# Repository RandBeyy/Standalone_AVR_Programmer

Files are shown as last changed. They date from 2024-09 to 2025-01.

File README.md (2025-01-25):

This project is based on Nick Gammon's ATmega_Hex_Uploader.
I added the LCD2004 to the project and design PCB so this device look more decent.
The main reason of this project is to make a small device to program a lot of MCUs like Attiny45
with simple and easy interface and without a computer. 
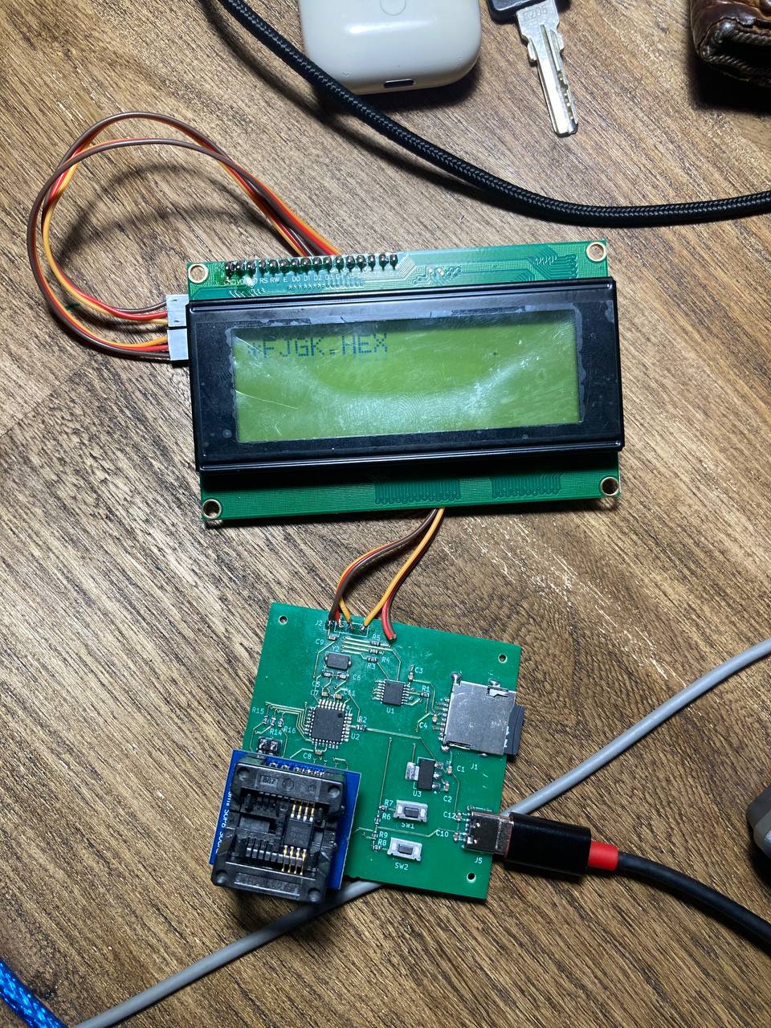
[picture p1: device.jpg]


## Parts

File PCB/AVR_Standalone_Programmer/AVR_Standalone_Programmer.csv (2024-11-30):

Id | Designator | Footprint | Quantity | Designation | Supplier and ref
1 | R4,R1,R3,R5 | R_0603_1608Metric | 4 | 3.3k
2 | R14,R16,R15 | R_0603_1608Metric | 3 | 330R
3 | C9,C10,C2,C12,C8 | C_0603_1608Metric | 5 | 10uF
4 | U2 | TQFP-32_7x7mm_P0.8mm | 1 | ATmega328P-A
5 | J1 | CUI_MSD-3-A | 1 | MSD-3-A
6 | H1,H3,H4,H2 | MountingHole_2.2mm_M2 | 4 | MountingHole
7 | R11,R13,R10,R12 | R_0603_1608Metric | 4 | 0R
8 | J4,J3 | PinSocket_1x04_P2.54mm_Vertical | 2 | Conn_01x04_Socket
9 | R8,R2,R7 | R_0603_1608Metric | 3 | 1k
10 | U3 | SOT-223-3_TabPin2 | 1 | LD1117S33TR_SOT223
11 | C11,C1,C3,C4,C7 | C_0603_1608Metric | 5 | 100nF
12 | J5 | USB_C_Receptacle_GCT_USB4125-xx-x_6P_TopMnt_Horizontal | 1 | USB_C_Receptacle_PowerOnly_6P
13 | U1 | SOT402-1_NEX | 1 | 74LVC125APW
14 | C6,C5 | C_0805_2012Metric | 2 | 22uF
15 | J6 | PinHeader_2x03_P2.54mm_Vertical | 1 | AVR-ISP-6
16 | J2 | PinHeader_1x04_P2.54mm_Vertical | 1 | Conn_01x04_Pin
17 | SW1,SW2 | SW_Push_SPST_NO_Alps_SKRK | 2 | SW_DPST_x2
18 | R17 | R_0603_1608Metric | 1 | 100
19 | R6,R9 | R_0603_1608Metric | 2 | 10k
20 | Y2 | Crystal_SMD_5032-2Pin_5.0x3.2mm | 1 | 16Mhz

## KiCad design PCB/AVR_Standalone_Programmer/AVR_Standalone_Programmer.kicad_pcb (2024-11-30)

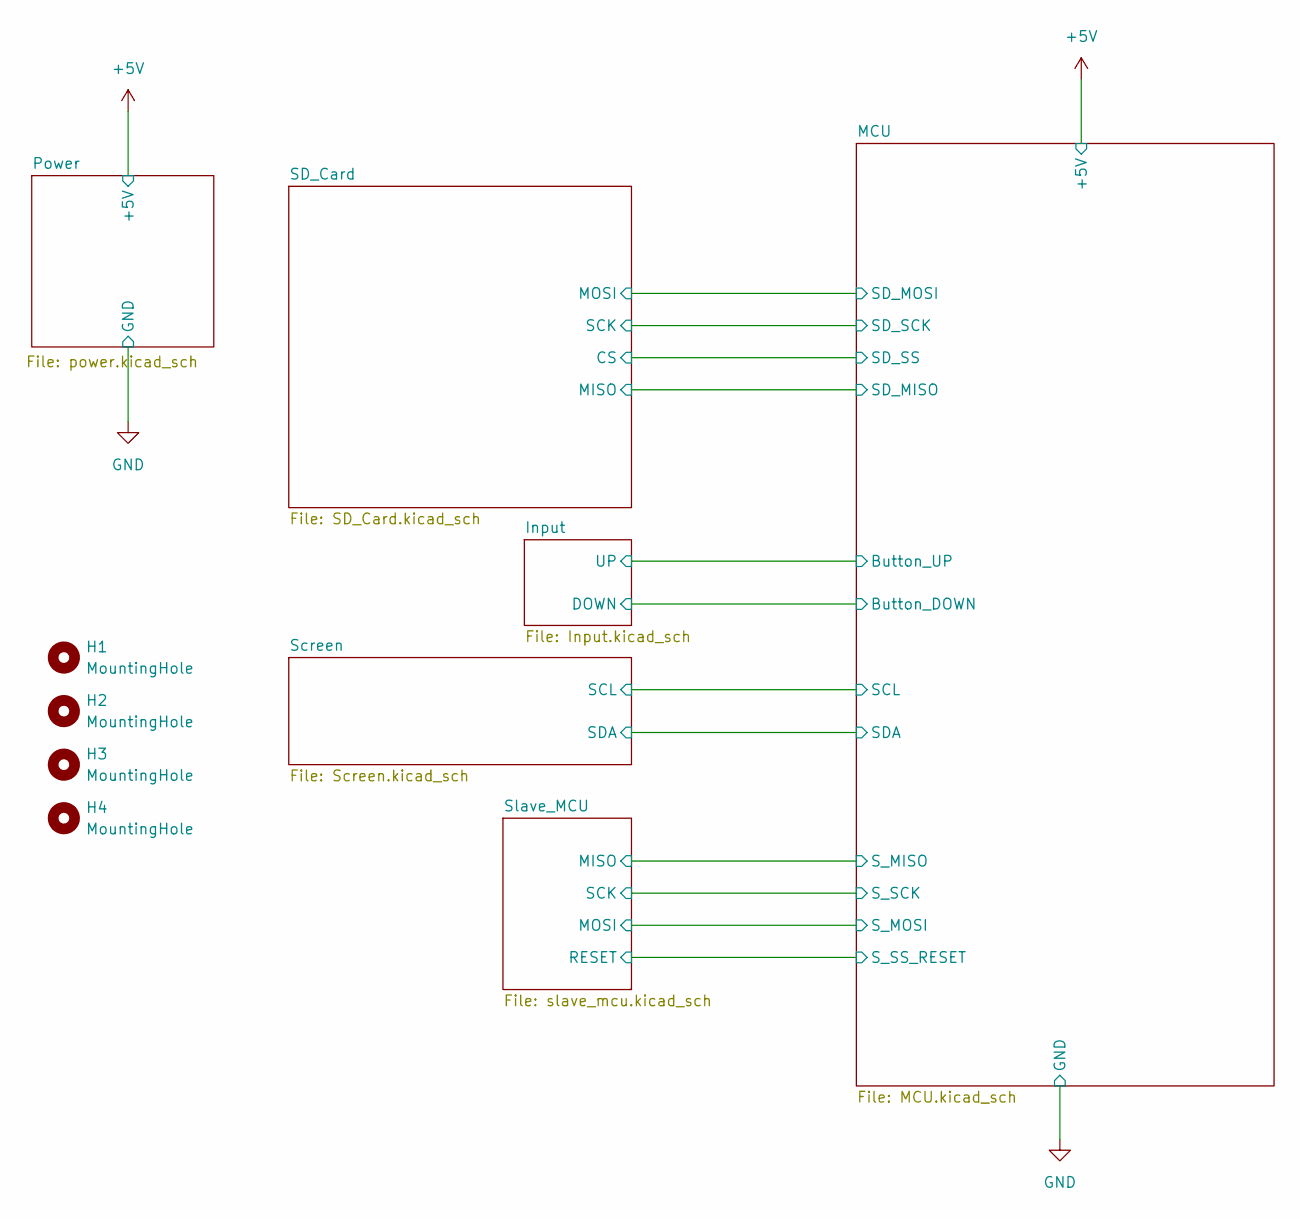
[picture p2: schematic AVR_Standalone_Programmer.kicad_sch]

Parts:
H1, H2, H3, H4: MountingHole; MountingHole_2.2mm_M2

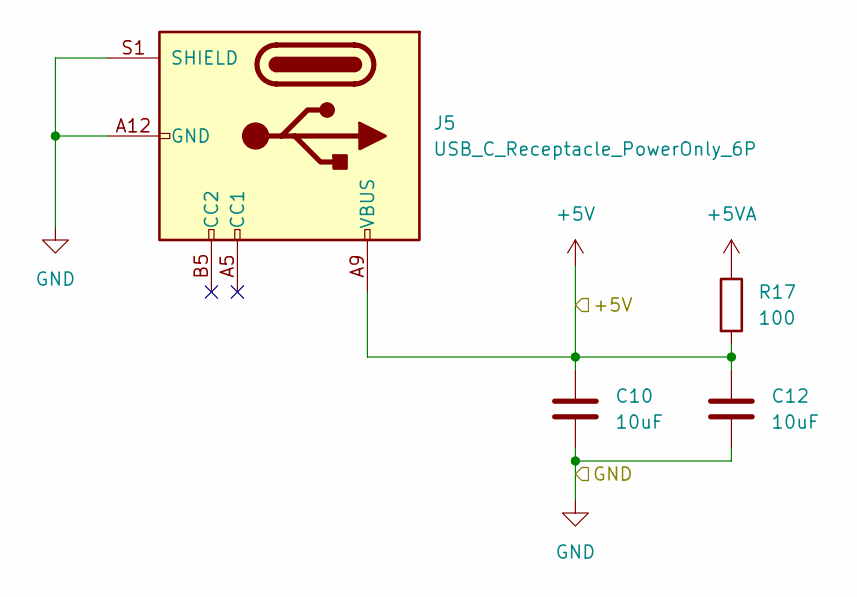
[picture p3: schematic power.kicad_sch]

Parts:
C10, C12: 10uF; C_0603_1608Metric
J5: USB_C_Receptacle_PowerOnly_6P; USB_C_Receptacle_GCT_USB4125-xx-x_6P_TopMnt_Horizontal
R17: 100; R_0603_1608Metric

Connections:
+5V: C10.1, C12.1, J5.A9 (VBUS), J5.B9 (VBUS), R17.2; also elsewhere on the board
+5VA: R17.1; also elsewhere on the board
GND: C10.2, C12.2, J5.A12 (GND), J5.B12 (GND), J5.S1 (SHIELD); also elsewhere on the board

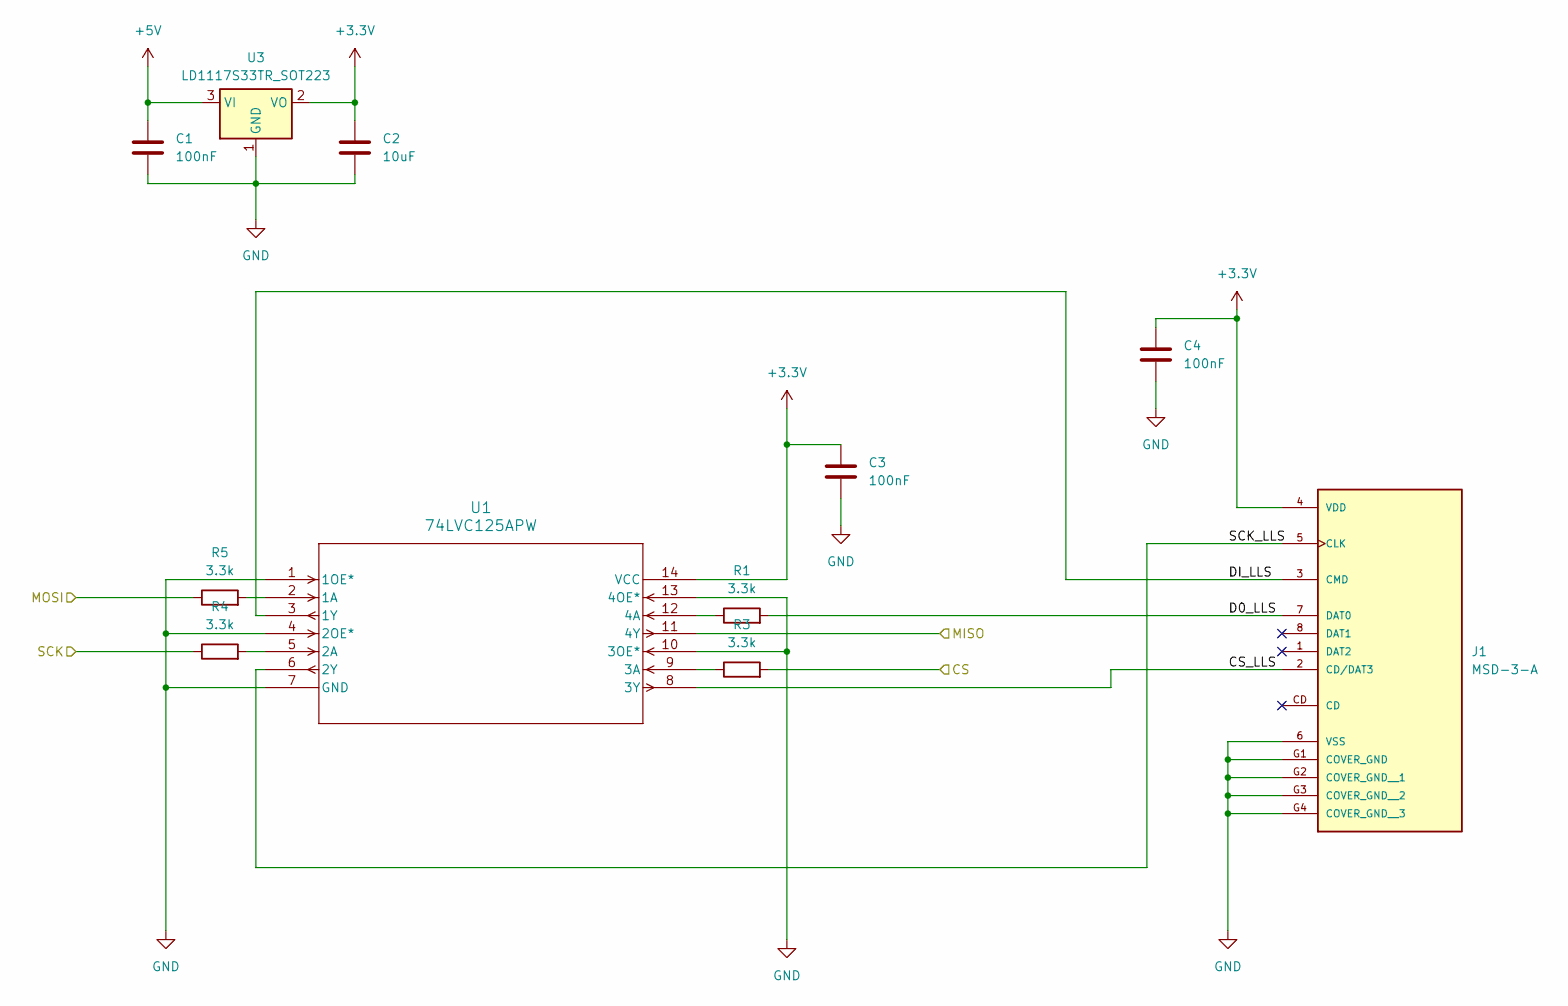
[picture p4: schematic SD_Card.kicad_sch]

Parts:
C1, C3, C4: 100nF; C_0603_1608Metric
C2: 10uF; C_0603_1608Metric
J1: MSD-3-A; CUI_MSD-3-A; PARTREV 1.0
R1, R3, R4, R5: 3.3k; R_0603_1608Metric
U1: 74LVC125APW; SOT402-1_NEX
U3: LD1117S33TR_SOT223; SOT-223-3_TabPin2

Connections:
+3.3V: C2.1, C3.1, C4.1, J1.4 (VDD), U1.14 (VCC), U3.2 (VO)
+5V: C1.1, U3.3 (VI); also elsewhere on the board
/MCU/MISO: U1.11 (4Y); also elsewhere on the board
/MCU/MOSI: R5.1; also elsewhere on the board
/MCU/SCK: R4.1; also elsewhere on the board
/MCU/SD_SS: R3.2; also elsewhere on the board
/SD_Card/CS_LLS: J1.2 (CD/DAT3), U1.8 (3Y)
/SD_Card/D0_LLS: J1.7 (DAT0), R1.2
/SD_Card/DI_LLS: J1.3 (CMD), U1.3 (1Y)
/SD_Card/SCK_LLS: J1.5 (CLK), U1.6 (2Y)
GND: C1.2, C2.2, C3.2, C4.2, J1.6 (VSS), J1.G1 (COVER_GND), J1.G2 (COVER_GND__1), J1.G3 (COVER_GND__2), J1.G4 (COVER_GND__3), U1.1 (1OE*), U1.4 (2OE*), U1.7 (GND), U1.10 (3OE*), U1.13 (4OE*), U3.1 (GND); also elsewhere on the board
unnamed: R5.2, U1.2 (1A)
unnamed: R4.2, U1.5 (2A)
unnamed: R3.1, U1.9 (3A)
unnamed: R1.1, U1.12 (4A)

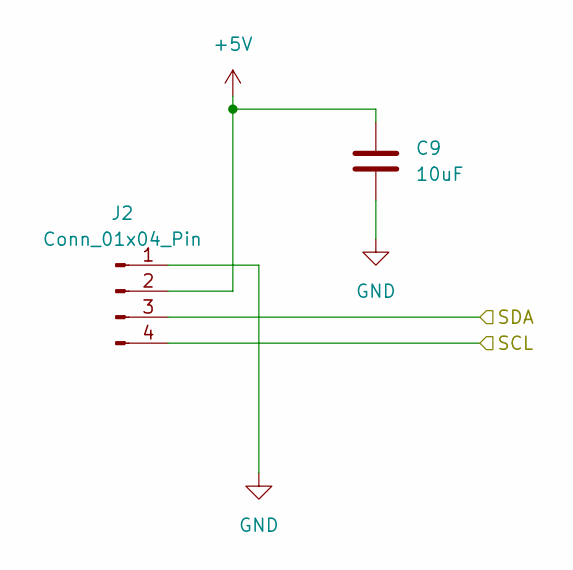
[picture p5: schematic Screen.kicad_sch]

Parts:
C9: 10uF; C_0603_1608Metric
J2: Conn_01x04_Pin; PinHeader_1x04_P2.54mm_Vertical

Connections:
+5V: C9.1, J2.2; also elsewhere on the board
/MCU/SCL: J2.4; also elsewhere on the board
/MCU/SDA: J2.3; also elsewhere on the board
GND: C9.2, J2.1; also elsewhere on the board

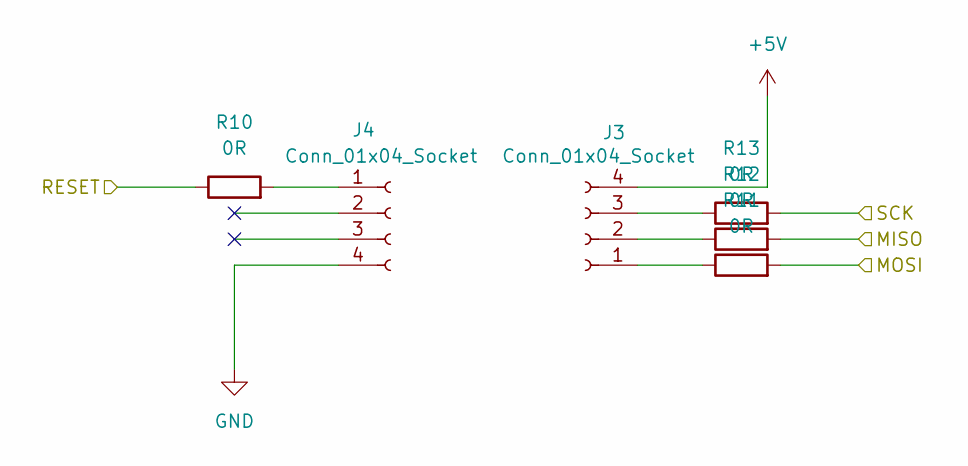
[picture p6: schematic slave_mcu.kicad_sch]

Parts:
J3, J4: Conn_01x04_Socket; PinSocket_1x04_P2.54mm_Vertical
R10, R11, R12, R13: 0R; R_0603_1608Metric

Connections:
+5V: J3.4; also elsewhere on the board
/MCU/S_MISO: R12.2; also elsewhere on the board
/MCU/S_MOSI: R11.2; also elsewhere on the board
/MCU/S_SCK: R13.2; also elsewhere on the board
/MCU/S_SS_RESET: R10.1; also elsewhere on the board
GND: J4.4; also elsewhere on the board
unnamed: J3.1, R11.1
unnamed: J3.2, R12.1
unnamed: J3.3, R13.1
unnamed: J4.1, R10.2

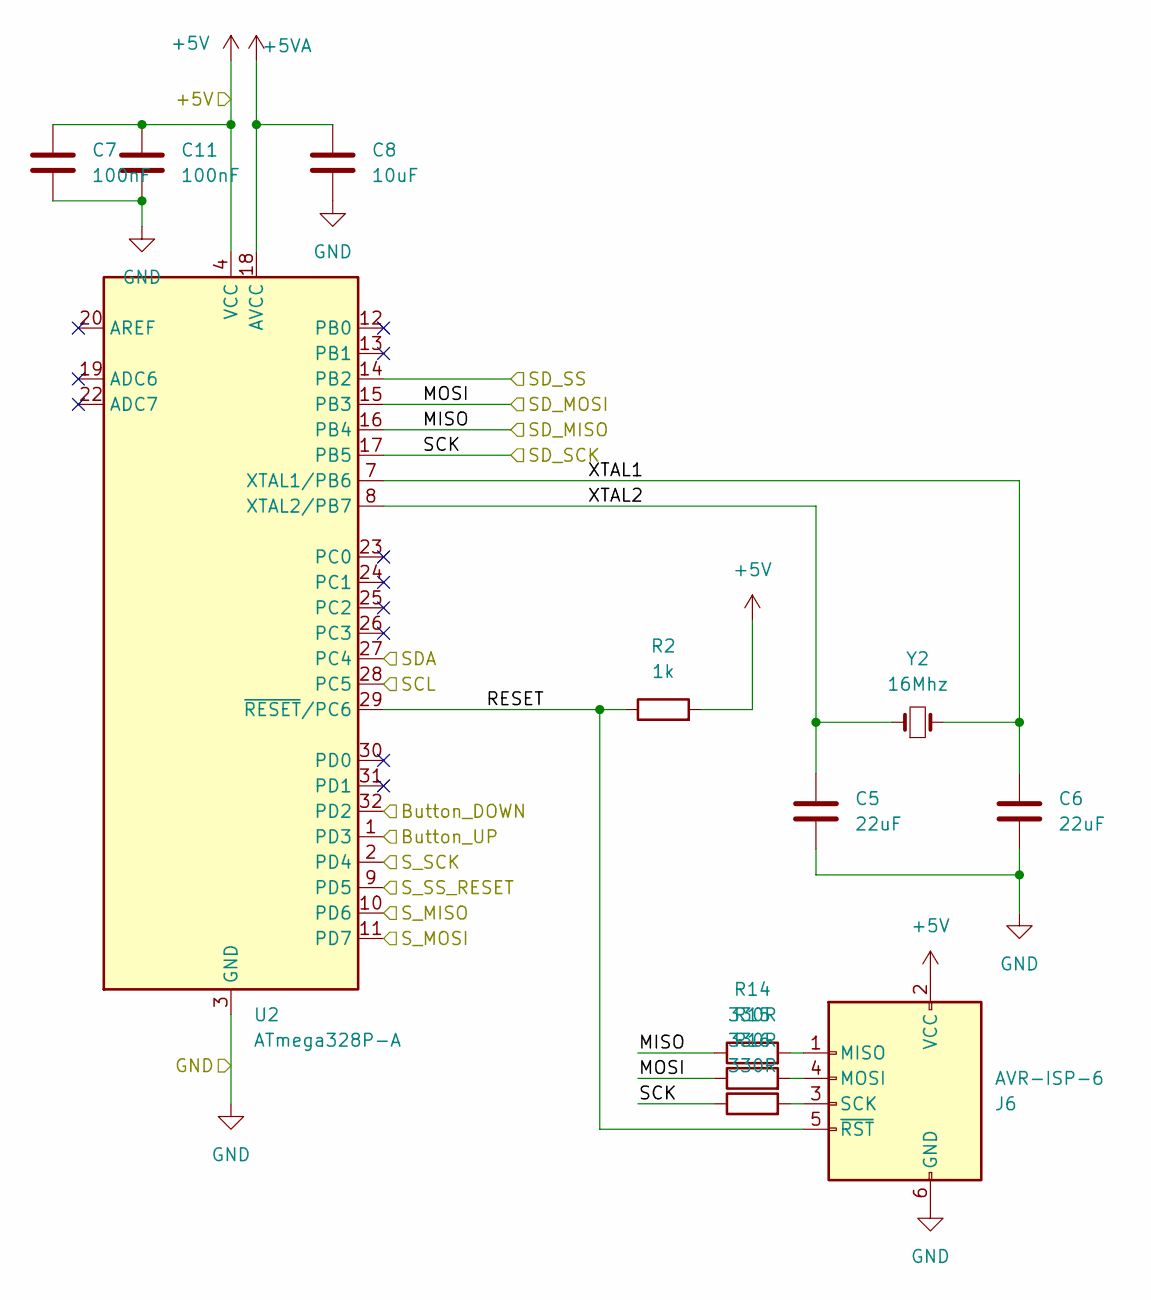
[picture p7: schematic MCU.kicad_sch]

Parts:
C5, C6: 22uF; C_0805_2012Metric
C7, C11: 100nF; C_0603_1608Metric
C8: 10uF; C_0603_1608Metric
J6: AVR-ISP-6; PinHeader_2x03_P2.54mm_Vertical
R2: 1k; R_0603_1608Metric
R14, R15, R16: 330R; R_0603_1608Metric
U2: ATmega328P-A; TQFP-32_7x7mm_P0.8mm
Y2: 16Mhz; Crystal_SMD_5032-2Pin_5.0x3.2mm

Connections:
+5V: C7.1, C11.1, J6.2 (VCC), R2.2, U2.4 (VCC), U2.6 (VCC); also elsewhere on the board
+5VA: C8.1, U2.18 (AVCC); also elsewhere on the board
/Input/DOWN: U2.32 (PD2); also elsewhere on the board
/Input/UP: U2.1 (PD3); also elsewhere on the board
/MCU/MISO: R14.1, U2.16 (PB4); also elsewhere on the board
/MCU/MOSI: R15.1, U2.15 (PB3); also elsewhere on the board
/MCU/RESET: J6.5 (~RST), R2.1, U2.29 (~RESET/PC6)
/MCU/SCK: R16.1, U2.17 (PB5); also elsewhere on the board
/MCU/SCL: U2.28 (PC5); also elsewhere on the board
/MCU/SDA: U2.27 (PC4); also elsewhere on the board
/MCU/SD_SS: U2.14 (PB2); also elsewhere on the board
/MCU/S_MISO: U2.10 (PD6); also elsewhere on the board
/MCU/S_MOSI: U2.11 (PD7); also elsewhere on the board
/MCU/S_SCK: U2.2 (PD4); also elsewhere on the board
/MCU/S_SS_RESET: U2.9 (PD5); also elsewhere on the board
/MCU/XTAL1: C6.1, U2.7 (XTAL1/PB6), Y2.2
/MCU/XTAL2: C5.1, U2.8 (XTAL2/PB7), Y2.1
GND: C5.2, C6.2, C7.2, C8.2, C11.2, J6.6 (GND), U2.3 (GND), U2.5 (GND), U2.21 (GND); also elsewhere on the board
unnamed: J6.1 (MISO), R14.2
unnamed: J6.4 (MOSI), R15.2
unnamed: J6.3 (SCK), R16.2

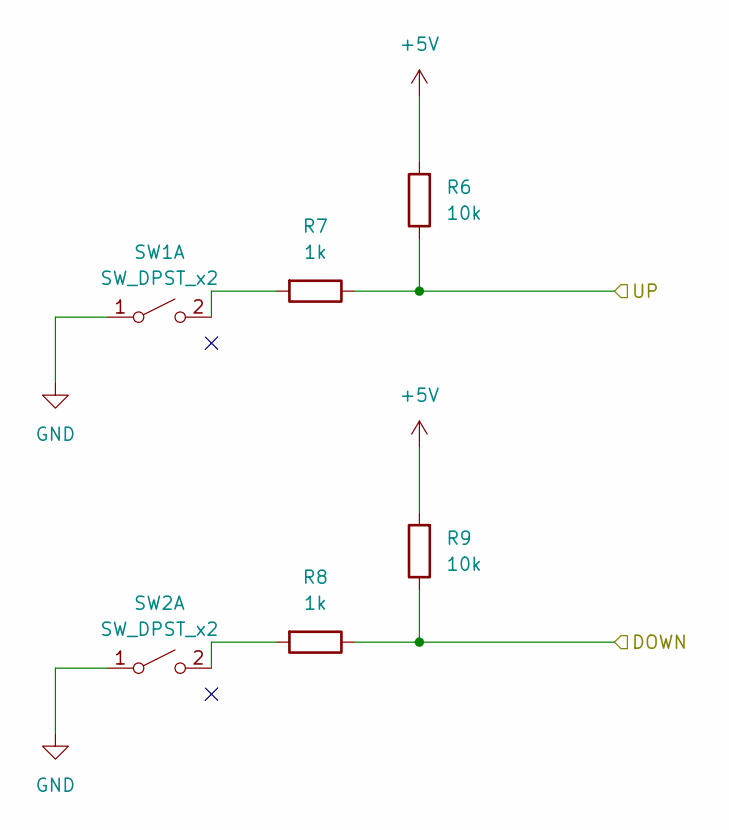
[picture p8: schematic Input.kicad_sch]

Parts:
R6, R9: 10k; R_0603_1608Metric
R7, R8: 1k; R_0603_1608Metric
SW1, SW2: SW_DPST_x2; SW_Push_SPST_NO_Alps_SKRK

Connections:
+5V: R6.2, R9.2; also elsewhere on the board
/Input/DOWN: R8.1, R9.1; also elsewhere on the board
/Input/UP: R6.1, R7.1; also elsewhere on the board
GND: SW1.1 (A), SW2.1 (A); also elsewhere on the board
unnamed: R7.2, SW1.2 (B)
unnamed: R8.2, SW2.2 (B)

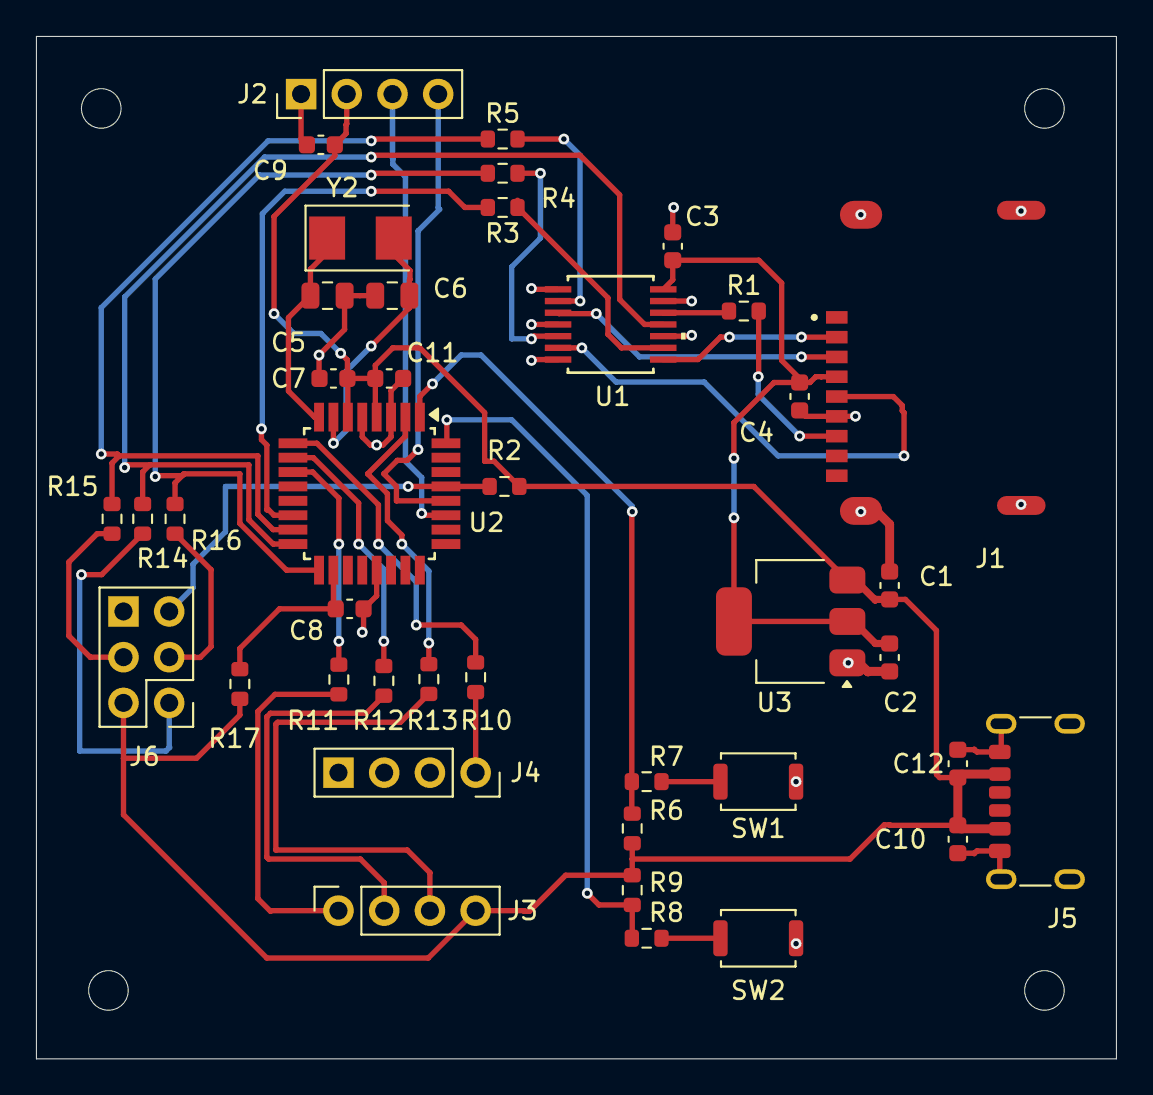
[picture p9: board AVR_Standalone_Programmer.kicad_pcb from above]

Board: 2 copper layers, 60.0 x 56.8 mm, 45 parts (0 on the bottom side), 36 nets.

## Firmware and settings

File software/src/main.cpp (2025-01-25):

const bool allowTargetToRun = true;  // if true, programming lines are freed when not programming

#define ALLOW_MODIFY_FUSES false   // make false if this sketch doesn't fit into memory
#define ALLOW_FILE_SAVING false    // make false if this sketch doesn't fit into memory
#define SAFETY_CHECKS true        // check for disabling SPIEN, or enabling RSTDISBL

#define USE_ETHERNET_SHIELD false  // Use the Arduino Ethernet Shield for the SD card

// make true if you have spare pins for the SD card interface
#define SD_CARD_ACTIVE true

// make true to use the high-voltage parallel wiring
#define HIGH_VOLTAGE_PARALLEL false
// make true to use the high-voltage serial wiring
#define HIGH_VOLTAGE_SERIAL false
// make true to use ICSP programming
#define ICSP_PROGRAMMING true

// make true to use bit-banged SPI for programming
#define USE_BIT_BANGED_SPI true

#if HIGH_VOLTAGE_PARALLEL && HIGH_VOLTAGE_SERIAL
  #error Cannot use both high-voltage parallel and serial at the same time
#endif

#if (HIGH_VOLTAGE_PARALLEL || HIGH_VOLTAGE_SERIAL) && ICSP_PROGRAMMING
  #error Cannot use ICSP and high-voltage programming at the same time
#endif

#if !(HIGH_VOLTAGE_PARALLEL || HIGH_VOLTAGE_SERIAL || ICSP_PROGRAMMING)
  #error Choose a programming mode: HIGH_VOLTAGE_PARALLEL, HIGH_VOLTAGE_SERIAL or ICSP_PROGRAMMING
#endif

#if !USE_BIT_BANGED_SPI && SD_CARD_ACTIVE
  #error If you are using an SD card you need to use bit-banged SPI for the programmer
#endif


/*

 For more details, photos, wiring, instructions, see:

    http://www.gammon.com.au/forum/?id=11638


 Copyright 2012 Nick Gammon.


 PERMISSION TO DISTRIBUTE

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

 LIMITATION OF LIABILITY

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
*/

// for SDFat library see: https://github.com/greiman/SdFat
#include "SdFat.h"
//#include <SdFat.h>
#include <Arduino.h>
#include <avr/eeprom.h>

// #include <memdebug.h>

const char Version [] = "1.37";

const unsigned int ENTER_PROGRAMMING_ATTEMPTS = 50;

#include "HV_Pins.h"
#include "Signatures.h"
#include "General_Stuff.h"
//#include "File_Utils.cpp"
#include "HV_Serial_Utils.cpp"
#include "HV_Parallel_Utils.cpp"
#include <Wire.h>             // Include the Wire library for I2C communication
#include <LiquidCrystal_I2C.h>

LiquidCrystal_I2C lcd(0x27, 20, 4); // Creates I2C LCD Object With (Address=0x27, Cols=20, Rows=4)

// target board reset goes to here
const uint8_t RESET = 5;
// 8 MHz clock on this pin
const uint8_t CLOCKOUT = 9;

#if USE_BIT_BANGED_SPI

  // bit banged SPI pins
  #ifdef __AVR_ATmega2560__
    // Atmega2560
    #if USE_ETHERNET_SHIELD
      const uint8_t MSPIM_SCK = 3;  // port E bit 5
    #else
      const uint8_t MSPIM_SCK = 4;  // port G bit 5
    #endif
    const uint8_t MSPIM_SS  = 5;  // port E bit 3
    const uint8_t BB_MISO   = 6;  // port H bit 3
    const uint8_t BB_MOSI   = 7;  // port H bit 4
  #elif defined(__AVR_ATmega1284P__)
    // Atmega1284P
    const uint8_t MSPIM_SCK = 11;  // port D bit 3
    const uint8_t MSPIM_SS  = 12;  // port D bit 4
    const uint8_t BB_MISO   = 13;  // port D bit 5
    const uint8_t BB_MOSI   = 14;  // port D bit 6
  #else
    // Atmega328
    #if USE_ETHERNET_SHIELD
      const uint8_t MSPIM_SCK = 3;  // port D bit 3
    #else
      const uint8_t MSPIM_SCK = 4;  // port D bit 4
    #endif
    const uint8_t MSPIM_SS  = 5;  // port D bit 5
    const uint8_t BB_MISO   = 6;  // port D bit 6
    const uint8_t BB_MOSI   = 7;  // port D bit 7
  #endif


  /*

  Connect target processor like this:

    D4: (SCK)   --> SCK as per datasheet (If using Ethernet shield, use D3 instead)
    D5: (SS)    --> goes to /RESET on target
    D6: (MISO)  --> MISO as per datasheet
    D7: (MOSI)  --> MOSI as per datasheet

    D9: 8 Mhz clock signal if required by target

  Connect SD card like this:

    D10: SS   (chip select)
    D11: MOSI (DI - data into SD card)
    D12: MISO (DO - data out from SD card)
    D13: SCK  (CLK - clock)

  Both SD card and target processor will need +5V and Gnd connected.

  */

  // for fast port access
  #ifdef __AVR_ATmega2560__
    // Atmega2560
    #define BB_MISO_PORT PINH
    #define BB_MOSI_PORT PORTH
    #if USE_ETHERNET_SHIELD
      #define BB_SCK_PORT PORTE   // Pin D3
    #else
      #define BB_SCK_PORT PORTG   // Pind D4
    #endif
    const uint8_t BB_SCK_BIT = 5;
    const uint8_t BB_MISO_BIT = 3;
    const uint8_t BB_MOSI_BIT = 4;
  #elif defined(__AVR_ATmega1284P__)
    // Atmega1284P
    #define BB_MISO_PORT PIND
    #define BB_MOSI_PORT PORTD
    #define BB_SCK_PORT PORTD
    const uint8_t BB_SCK_BIT = 3;
    const uint8_t BB_MISO_BIT = 5;
    const uint8_t BB_MOSI_BIT = 6;
  #else
    // Atmega328
    #define BB_MISO_PORT PIND
    #define BB_MOSI_PORT PORTD
    #define BB_SCK_PORT PORTD
    #if USE_ETHERNET_SHIELD
      const uint8_t BB_SCK_BIT = 3;  // Pin D3
    #else
      const uint8_t BB_SCK_BIT = 4;  // Pind D4
    #endif
    const uint8_t BB_MISO_BIT = 6;
    const uint8_t BB_MOSI_BIT = 7;
  #endif

  // control speed of programming
  const uint8_t BB_DELAY_MICROSECONDS = 6;



#endif // USE_BIT_BANGED_SPI


#if SD_CARD_ACTIVE
  // SD chip select pin
  #if USE_ETHERNET_SHIELD
    const uint8_t chipSelect = 4;   // Ethernet shield uses D4 as SD select
  #else
    const uint8_t chipSelect = SS;  // Otherwise normal slave select
  #endif

  const int MAX_FILENAME = 13;
  void * LAST_FILENAME_LOCATION_IN_EEPROM = 0;

  // file system object
  SdFat sd;
#endif

// actions to take
enum {
    checkFile,
    verifyFlash,
    writeToFlash,
};

unsigned long lowestAddress;
unsigned long highestAddress;
unsigned long bytesWritten;
bool haveSDcard;

#pragma region Func_Declaration

void writeFlash (unsigned long addr, const uint8_t data);
uint8_t BB_SPITransfer (uint8_t c);
void showProgress ();
bool hexConv (const char * (& pStr), uint8_t & b);
void verifyData (const unsigned long addr, const uint8_t * pData, const int length);
void writeData (const unsigned long addr, const uint8_t * pData, const int length);
void eraseMemory ();
bool updateFuses (const bool writeIt);
bool startProgramming ();
void getline (char * buf, size_t bufsize);
bool getYesNo ();
uint8_t readFlash (unsigned long addr);
void displayMessage(const char* message, int delayTime=400);
void getSignature ();
void getFuseBytes ();
bool chooseInputFile();
void showFileMenu();

#pragma endregion

int progressBarCol = 0;
int currentMenu = 0; // 0 - головне меню, 1 - підменю
int currentSelection = 0;


#pragma region File_Utils

// File_Utils.ino
//
// Functions related to the SD card (if present) including listing the directory,
// and reading an interpreting a .HEX file.
//
// Author: Nick Gammon



#if SD_CARD_ACTIVE

// types of record in .hex file
enum {
    hexDataRecord,  // 00
    hexEndOfFile,   // 01
    hexExtendedSegmentAddressRecord, // 02
    hexStartSegmentAddressRecord,  // 03
    hexExtendedLinearAddressRecord, // 04
    hexStartLinearAddressRecord // 05
};

bool gotEndOfFile;
unsigned long extendedAddress;
unsigned int lineCount;

/*
Line format:

  :nnaaaatt(data)ss

  Where:
  :      = a colon

  (All of below in hex format)

  nn     = length of data part
  aaaa   = address (eg. where to write data)
  tt     = transaction type
           00 = data
           01 = end of file
           02 = extended segment address (changes high-order byte of the address)
           03 = start segment address *
           04 = linear address *
           05 = start linear address *
  (data) = variable length data
  ss     = sumcheck

            * We don't use these

*/

char name[MAX_FILENAME] = { 0 };  // current file name

bool processLine (const char * pLine, const byte action)
  {
  if (*pLine++ != ':')
     {
     Serial.println (F("Line does not start with ':' character."));
     return true;  // error
     }

  const int maxHexData = 40;
  byte hexBuffer [maxHexData];
  int bytesInLine = 0;

  if (action == checkFile)
    if (lineCount++ % 40 == 0)
      showProgress ();

  // convert entire line from ASCII into binary
  while (isxdigit (*pLine))
    {
    // can't fit?
    if (bytesInLine >= maxHexData)
      {
      Serial.println (F("Line too long to process."));
      return true;
      } // end if too long

    if (hexConv (pLine, hexBuffer [bytesInLine++]))
      return true;
    }  // end of while

  if (bytesInLine < 5)
    {
    Serial.println (F("Line too short."));
    return true;
    }

  // sumcheck it

  byte sumCheck = 0;
  for (int i = 0; i < (bytesInLine - 1); i++)
    sumCheck += hexBuffer [i];

  // 2's complement
  sumCheck = ~sumCheck + 1;

  // check sumcheck
  if (sumCheck != hexBuffer [bytesInLine - 1])
    {
    Serial.print (F("Sumcheck error. Expected: "));
    showHex (sumCheck);
    Serial.print (F(", got: "));
    showHex (hexBuffer [bytesInLine - 1], true);
    return true;
    }

  // length of data (eg. how much to write to memory)
  byte len = hexBuffer [0];

  // the data length should be the number of bytes, less
  //   length / address (2) / transaction type / sumcheck
  if (len != (bytesInLine - 5))
    {
    Serial.print (F("Line not expected length. Expected "));
    Serial.print (len, DEC);
    Serial.print (F(" bytes, got "));
    Serial.print (bytesInLine - 5, DEC);
    Serial.println (F(" bytes."));
    return true;
    }

  // two bytes of address
  unsigned long addrH = hexBuffer [1];
  unsigned long addrL = hexBuffer [2];

  unsigned long addr = addrL | (addrH << 8);

  byte recType = hexBuffer [3];

  switch (recType)
    {
    // stuff to be written to memory
    case hexDataRecord:
      lowestAddress  = min (lowestAddress, addr + extendedAddress);
      highestAddress = max (lowestAddress, addr + extendedAddress + len - 1);
      bytesWritten += len;

      switch (action)
        {
        case checkFile:  // nothing much to do, we do the checks anyway
          break;

        case verifyFlash:
          verifyData (addr + extendedAddress, &hexBuffer [4], len);
          break;

        case writeToFlash:
          writeData (addr + extendedAddress, &hexBuffer [4], len);
          break;
        } // end of switch on action
      break;

    // end of data
    case hexEndOfFile:
      gotEndOfFile = true;
      break;

    // we are setting the high-order byte of the address
    case hexExtendedSegmentAddressRecord:
      extendedAddress = ((unsigned long) hexBuffer [4]) << 12;
      break;

    // ignore these, who cares?
    case hexStartSegmentAddressRecord:
    case hexExtendedLinearAddressRecord:
    case hexStartLinearAddressRecord:
      break;

    default:
      Serial.print (F("Cannot handle record type: "));
      Serial.println (recType, DEC);
      return true;
    }  // end of switch on recType

  return false;
  } // end of processLine

//------------------------------------------------------------------------------
bool readHexFile (const char * fName, const byte action)
  {
  const int maxLine = 80;
  char buffer[maxLine];
  ifstream sdin (fName);
  int lineNumber = 0;
  gotEndOfFile = false;
  extendedAddress = 0;
  errors = 0;
  lowestAddress = 0xFFFFFFFF;
  highestAddress = 0;
  bytesWritten = 0;
  progressBarCount = 0;

  pagesize = currentSignature.pageSize;
  pagemask = ~(pagesize - 1);
  oldPage = NO_PAGE;

  Serial.print (F("Processing file: "));
  Serial.println (fName);

  // check for open error
  if (!sdin.is_open())
    {
    Serial.println (F("Could not open file."));
    return true;
    }

  switch (action)
    {
    case checkFile:
      Serial.println (F("Checking file ..."));
      break;

    case verifyFlash:
      Serial.println (F("Verifying flash ..."));
      break;

    case writeToFlash:
      Serial.println (F("Erasing chip ..."));
      eraseMemory ();
      Serial.println (F("Writing flash ..."));
      break;
    } // end of switch

  while (sdin.getline (buffer, maxLine))
    {
    lineNumber++;
    int count = sdin.gcount();
    if (sdin.fail())
      {
      Serial.print (F("Line "));
      Serial.println (lineNumber);
      Serial.print (F(" too long."));
      return true;
      }  // end of fail (line too long?)

    // ignore empty lines
    if (count > 1)
      {
      if (processLine (buffer, action))
        {
        Serial.print (F("Error in line "));
        Serial.println (lineNumber);
        return true;  // error
        }
      }
    }    // end of while each line

  if (!gotEndOfFile)
    {
    Serial.println (F("Did not get 'end of file' record."));
    return true;
    }

  switch (action)
    {
    case writeToFlash:
      // commit final page
      if (oldPage != NO_PAGE)
        commitPage (oldPage);
      Serial.println ();   // finish line of dots
      Serial.println (F("Written."));
      break;

    case verifyFlash:
       Serial.println ();   // finish line of dots
       if (errors == 0)
          Serial.println (F("No errors found."));
        else
          {
          Serial.print (errors, DEC);
          Serial.println (F(" verification error(s)."));
          if (errors > 100)
            Serial.println (F("First 100 shown."));
          }  // end if
       break;

    case checkFile:
      Serial.println ();   // finish line of dots
      Serial.print (F("Lowest address  = 0x"));
      Serial.println (lowestAddress, HEX);
      Serial.print (F("Highest address = 0x"));
      Serial.println (highestAddress, HEX);
      Serial.print (F("Bytes to write  = "));
      Serial.println (bytesWritten, DEC);
      break;

    }  // end of switch

  return false;
}  // end of readHexFile

char firmwareFiles[11][MAX_FILENAME];

void getFirmwareFiles(){
  if (!haveSDcard)
    {
    Serial.println (F("*** No SD card detected."));
    displayMessage("No SD card detected");
    return;
    }
  SdFile file;
  char name[MAX_FILENAME];
  

  sd.vwd()->rewind();
  int count = 0;
  while (file.openNext(sd.vwd(), O_READ) && count < 10) {
    file.getFilename(name);
    byte len = strlen (name);
    if (len > 4 && strcmp (&name [len - 4], ".HEX") == 0)
      {
        strcpy(firmwareFiles[count], name);
      count+=1;
      }
      file.close();
    }
    firmwareFiles[count][0] = '\0';
}

void showDirectory ()
  {
  if (!haveSDcard)
    {
    Serial.println (F("*** No SD card detected."));
    return;
    }

  // list files in root directory

  SdFile file;
  char name[MAX_FILENAME];

  Serial.println ();
  Serial.println (F("HEX files in root directory:"));
  Serial.println ();

  // back to start of directory
  sd.vwd()->rewind ();

  // open next file in root.  The volume working directory, vwd, is root
  while (file.openNext(sd.vwd(), O_READ)) {
    file.getFilename(name);
    byte len = strlen (name);
    if (len > 4 && strcmp (&name [len - 4], ".HEX") == 0)
      {
      Serial.print (name);
      for (byte i = strlen (name); i < 13; i++)
        Serial.write (' ');  // space out so dates line up
      Serial.print (F(" : "));
      char buf [12];
      sprintf (buf, "%10lu", file.fileSize ());

      Serial.print (buf);
      Serial.print (F(" bytes."));

      Serial.println ();
      }
    file.close();
    }  // end of listing files

  }  // end of showDirectory

char lastFileName [MAX_FILENAME] = { 0 };


bool chooseInputFile ()
  {
  strcpy(name,firmwareFiles[currentSelection]);

  if (readHexFile(name, checkFile))
    {
    Serial.println (F("***********************************"));
    return true;  // error, don't attempt to write
    }


  // check file would fit into device memory
  if (highestAddress > currentSignature.flashSize)
    {
    Serial.print (F("Highest address of 0x"));
    Serial.print (highestAddress, HEX);
    Serial.print (F(" exceeds available flash memory top 0x"));
    Serial.println (currentSignature.flashSize, HEX);
    Serial.println (F("***********************************"));
    return true;
    }

  // check start address makes sense
  if (updateFuses (false))
    {
    Serial.println (F("***********************************"));
    return true;
    }

   return false;
  }  // end of chooseInputFile

/*
#if ALLOW_FILE_SAVING
void readFlashContents ()
  {
  if (!haveSDcard)
    {
    Serial.println (F("*** No SD card detected."));
    return;
    }

  progressBarCount = 0;
  pagesize = currentSignature.pageSize;
  pagemask = ~(pagesize - 1);
  oldPage = NO_PAGE;
  byte lastMSBwritten = 0;

  char name[] = "firmware.hex";

  // ensure back in programming mode
  if (!startProgramming ())
    return;

  SdFile myFile;

  // open the file for writing
  if (!myFile.open(name, O_WRITE | O_CREAT | O_TRUNC))
    {
    Serial.print (F("Could not open file "));
    Serial.print (name);
    Serial.println (F(" for writing."));
    return;
    }

  byte memBuf [16];
  unsigned int i;
  char linebuf [50];
  byte sumCheck;

  Serial.println (F("Copying flash memory to SD card (disk) ..."));

  for (unsigned long address = 0; address < currentSignature.flashSize; address += sizeof memBuf)
    {
    bool allFF;

    unsigned long thisPage = address & pagemask;
    // page changed? show progress
    if (thisPage != oldPage && oldPage != NO_PAGE)
      showProgress ();
    // now this is the current page
    oldPage = thisPage;

    // don't write lines that are all 0xFF
    allFF = true;

    for (i = 0; i < sizeof memBuf; i++)
      {
      memBuf [i] = readFlash (address + i);
      if (memBuf [i] != 0xFF)
        allFF = false;
      }  // end of reading 16 bytes
    if (allFF)
      continue;

    byte MSB = address >> 16;
    if (MSB != lastMSBwritten)
      {
      sumCheck = 2 + 2 + (MSB << 4);
      sumCheck = ~sumCheck + 1;
      // hexExtendedSegmentAddressRecord (02)
      sprintf (linebuf, ":02000002%02X00%02X\r\n", MSB << 4, sumCheck);
      myFile.print (linebuf);
      lastMSBwritten = MSB;
      }  // end if different MSB

    sumCheck = 16 + lowByte (address) + highByte (address);
    sprintf (linebuf, ":10%04X00", (unsigned int) address & 0xFFFF);
    for (i = 0; i < sizeof memBuf; i++)
      {
      sprintf (&linebuf [(i * 2) + 9] , "%02X",  memBuf [i]);
      sumCheck += memBuf [i];
      }  // end of reading 16 bytes

    // 2's complement
    sumCheck = ~sumCheck + 1;
    // append sumcheck
    sprintf (&linebuf [(sizeof memBuf * 2) + 9] , "%02X\r\n",  sumCheck);

    myFile.clearWriteError ();
    myFile.print (linebuf);
    if (myFile.getWriteError ())
       {
       Serial.println ();  // finish off progress bar
       Serial.println (F("Error writing file."));
       myFile.close ();
       return;
       }   // end of an error

    }  // end of reading flash

  Serial.println ();  // finish off progress bar
  myFile.print (":00000001FF\r\n");    // end of file record
  myFile.close ();
  // ensure written to disk
  sd.vwd()->sync ();
  Serial.print (F("File "));
  Serial.print (name);
  Serial.println (F(" saved."));
  }  // end of readFlashContents
#endif
*/
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
void loop ()
{
  writeFlashContents();
  /*
if (once){
  if (!startProgramming ())
    {
    Serial.println (F("Halted."));
    stopProgramming ();
    while  (true)
      {}
    }  // end of could not enter programming mode

  getSignature ();
  getFuseBytes ();
  // don't have signature? don't proceed
  if (foundSig == -1)
    {
    Serial.println (F("Halted."));
    stopProgramming ();
    while  (true)
      {}
    }  // end of no signature
    once=false;
}
*/
/*
 // ask for verify or write
  Serial.println (F("Actions:"));
  Serial.println (F(" [E] erase flash"));
#if ALLOW_MODIFY_FUSES
  Serial.println (F(" [F] modify fuses"));
#endif

#if SD_CARD_ACTIVE
  if (haveSDcard)
    {
    Serial.println (F(" [L] list directory"));
#if ALLOW_FILE_SAVING
    Serial.println (F(" [R] read from flash (save to disk)"));
#endif
    Serial.println (F(" [V] verify flash (compare to disk)"));
    Serial.println (F(" [W] write to flash (read from disk)"));
    }  // end of if SD card detected
#endif // SD_CARD_ACTIVE

  Serial.println (F("Enter action:"));

  // discard any old junk
  while (Serial.available ())
    Serial.read ();

  // turn off programming outputs if required
  if (allowTargetToRun)
    stopProgramming ();

  char command;
  do
    {
    command = toupper (Serial.read ());
    } while (!isalpha (command));

  Serial.println (command);  // echo their input

  // re-start programming mode if required
  if (allowTargetToRun)
    if (!startProgramming ())
      {
      Serial.println (F("Halted."));
      while  (true)
        {}
      } // end of could not enter programming mode

  switch (command)
    {
#if SD_CARD_ACTIVE

  #if ALLOW_FILE_SAVING
      case 'R':
        readFlashContents ();
        break;
  #endif

      case 'W':
        writeFlashContents ();
        break;

      case 'V':
        verifyFlashContents ();
        break;
#endif // SD_CARD_ACTIVE

    case 'E':
      eraseFlashContents ();
      break;
#if ALLOW_MODIFY_FUSES
    case 'F':
      modifyFuses ();
      break;
#endif

#if SD_CARD_ACTIVE
    case 'L':
      showDirectory ();
      break;
#endif // SD_CARD_ACTIVE

    default:
      Serial.println (F("Unknown command."));
      break;
    }  // end of switch on command
*/
}  // end of loop

#pragma endregion

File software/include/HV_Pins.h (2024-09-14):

// HV_Pins.h
//
// Pin numbers and commands for high-voltage serial or parallel programming
//
// Author: Nick Gammon




#if HIGH_VOLTAGE_PARALLEL || HIGH_VOLTAGE_SERIAL

  // high-voltage programming commands we can send (when action is LOAD_COMMAND)
  enum {
        CMD_CHIP_ERASE       = 0b10000000,
        CMD_WRITE_FUSE_BITS  = 0b01000000,
        CMD_WRITE_LOCK_BITS  = 0b00100000,
        CMD_WRITE_FLASH      = 0b00010000,
        CMD_WRITE_EEPROM     = 0b00010001,
        CMD_READ_SIGNATURE   = 0b00001000,
        CMD_READ_FUSE_BITS   = 0b00000100,
        CMD_READ_FLASH       = 0b00000010,
        CMD_READ_EEPROM      = 0b00000011,
        CMD_NO_OPERATION     = 0b00000000,
        }; // end of commands

#endif // HIGH_VOLTAGE_PARALLEL || HIGH_VOLTAGE_SERIAL

#if HIGH_VOLTAGE_PARALLEL
  // pin assignments for parallel high-voltage programming
  
// Arduino pins                 Target pins
// ------------                 -----------------------
  const byte dataPins [8] = { 
    6,                        // 14 (PB0) (data bit 0)
    7,                        // 15 (PB1) (data bit 1)
    8,                        // 16 (PB2) (data bit 2)
    9,                        // 17 (PB3) (data bit 3)  
    10,                       // 18 (PB4) (data bit 4)
    11,                       // 19 (PB5) (data bit 5)  
    12,                       // 23 (PC0) (data bit 6)
    13                        // 24 (PC1) (data bit 7)
    };    // end of dataPins

  enum {                                        
      RDY     = A0,           //  3 (PD1) (low means busy)   
      OE      = A1,           //  4 (PD2) (low means output enabled)    
      WR      = A2,           //  5 (PD3) (low means write)    
      BS1     = A3,           //  6 (PD4)     
      XTAL1   = A4,           //  9 (XTAL1)     
      XA0     = A5,           // 11 (PD5)     
      XA1     =  2,           // 12 (PD6)     
      PAGEL   =  3,           // 13 (PD7)     
      BS2     =  4,           // 25 (PC2)     
      VCC     =  5,           // 7 and 20 (VCC and AVCC)
  };  // end of other pins                  
                                            
  
  /* Note: /RESET (Pin 1) is brought to 12V by connecting a transistor and MOSFET (high-side driver)
     via a RC network to (the target) VCC. R = 22k, C = 10 nF. This gives a delay of around 40 uS between
     VCC and /RESET. The transistor turns on the MOSFET, which switches +12V to /RESET.
     For transistor/MOSFET schematic see: http://www.gammon.com.au/images/Arduino/MOSFET_high_side_driver.png
     
          |------------------------------------------------------->  VCC and AVCC
          |
   D5 >---|--/\/\/\/\---|-----------> Transistor ---> MOSFET -----> /RESET
               22k      |
                       ===  10 nF
                        |
                        |
                        V
                       Gnd
       
     Also connect the grounds. Gnd to pins 8 and 22.
     Decoupling capacitors: 0.1 uF between VCC/AVCC (pins 7 and 20) and Gnd.
     Not connected on target: pins 2, 10, 21, 26, 27, 28.
  */
  
  // when XTAL1 is pulsed the settings in XA1 and XA0 control the action
  enum {
       ACTION_LOAD_ADDRESS,
       ACTION_LOAD_DATA,
       ACTION_LOAD_COMMAND,
       ACTION_IDLE
       };    // end of actions

       
#endif //  HIGH_VOLTAGE_PARALLEL

#if HIGH_VOLTAGE_SERIAL

// ATMEL ATTINY 25/45/85 / ARDUINO
//
//             +-\/-+
//    /RESET  1|    |8  VCC  
// (SCI) PB3  2|    |7  PB2 (SDO)
// (N/C) PB4  3|    |6  PB1 (SII) 
//       GND  4|    |5  PB0 (SDI)
//             +----+


// Arduino pins                                  Target pins
// ------------                                  -------------------
enum {
    VCC   = 3,  // VCC and /RESET (see above for comments)  (pin 8)
    SDI   = 4,  // Serial Data Input                --> PB0 (pin 5)
    SII   = 5,  // Serial Instruction Input         --> PB1 (pin 6)
    SDO   = 6,  // Serial Data Output               --> PB2 (pin 7)
    SCI   = 7,  // Serial Clock Input (min. 220nS)  --> PB3 (pin 2)
};

enum {
    SII_LOAD_COMMAND        = 0b01001100,
    SII_LOAD_ADDRESS_LOW    = 0b00001100,
    SII_LOAD_ADDRESS_HIGH   = 0b00011100,
    SII_READ_LOW_BYTE       = 0b01101000,
    SII_READ_HIGH_BYTE      = 0b01111000,
    SII_WRITE_LOW_BYTE      = 0b01100100,
    SII_WRITE_HIGH_BYTE     = 0b01110100,
    SII_LOAD_LOW_BYTE       = 0b00101100,
    SII_LOAD_HIGH_BYTE      = 0b00111100,
    SII_WRITE_EXTENDED_FUSE = 0b01100110,
    SII_PROGRAM_LOW_BYTE    = 0b01101101, 
    SII_PROGRAM_HIGH_BYTE   = 0b01111101,
    SII_READ_EEPROM         = 0b01101000,
    
    // various actions are latched in by ORing in this value
    SII_OR_MASK             = 0b00001100,
   
    };  // end of chip commands
        
#endif // HIGH_VOLTAGE_SERIAL

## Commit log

2024-10-12 change arduino uno to nano
2024-11-30 Add pcb files to directory, move all software related files to coresponding folder
    [AVR_Standalone_Programmer.csv, AVR_Standalone_Programmer.kicad_pcb, AVR_Standalone_Programmer.kicad_sch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]
2025-01-25 added message for missing MCU and 1s delay before starting
    [AVR_Standalone_Programmer.csv]
